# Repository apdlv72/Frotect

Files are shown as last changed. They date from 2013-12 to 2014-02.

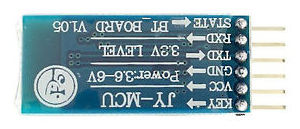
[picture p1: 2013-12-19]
schematic/HC-05/HC-05.JPG

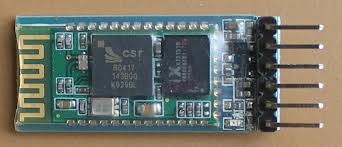
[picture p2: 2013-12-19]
schematic/HC-05/hc-05.jpeg

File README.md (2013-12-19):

Frotect
=======

Arduino sketch to protect sensitive plants from frost damage. Uses DS18B20  temperature sensors and solid state relays to switch light strands on/off.
You need the DallasTemperature arduino library to compile the sketch. 

The device can control up to four strands (however this should not be a hard limit if you are willing to adjust some #defines) and up to 5 sensors.
You can define lower and upper temperature threshold per strand where it should be swicthed on/off. I used it in my garden to protect some young,
exotic plants to survive their first winter in Germany. I mounted the light strips around a simple plastic schaffold and enwrapped the whole setup
with protective popup covers, not only to minimize heat discipation, but also to protect the plants from winter storms and sunshine (yes - that in fact
is the most likely reason for e.g. Olive trees dying in norther areas, not the coldness).

The device will also do some data logging of min/max temperatures, record the duty cycle per strand and even compute overall costs.
The device communicates (actuall it can, there's no need to do so) with the outside world via a Bluetooth module and can be controlled
via simple commands sent to it with a PC/laptop or an Android app. See the folder android for details.

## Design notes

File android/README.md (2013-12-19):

Frotect Android App
=======

This is an Android app that ic capable of connectiong to the Arduino via Bluetooth and control its operation. 
If you are interested in teh Code, feel free to contact me. Did not yet release the code, because I need to
separate the code specific for Frotect from a larger App that I use to control different devices in my house 
(LED strips, garage door opener etc.).

For now you can find some screen shots of the main activity and various config and statistics dialogs.

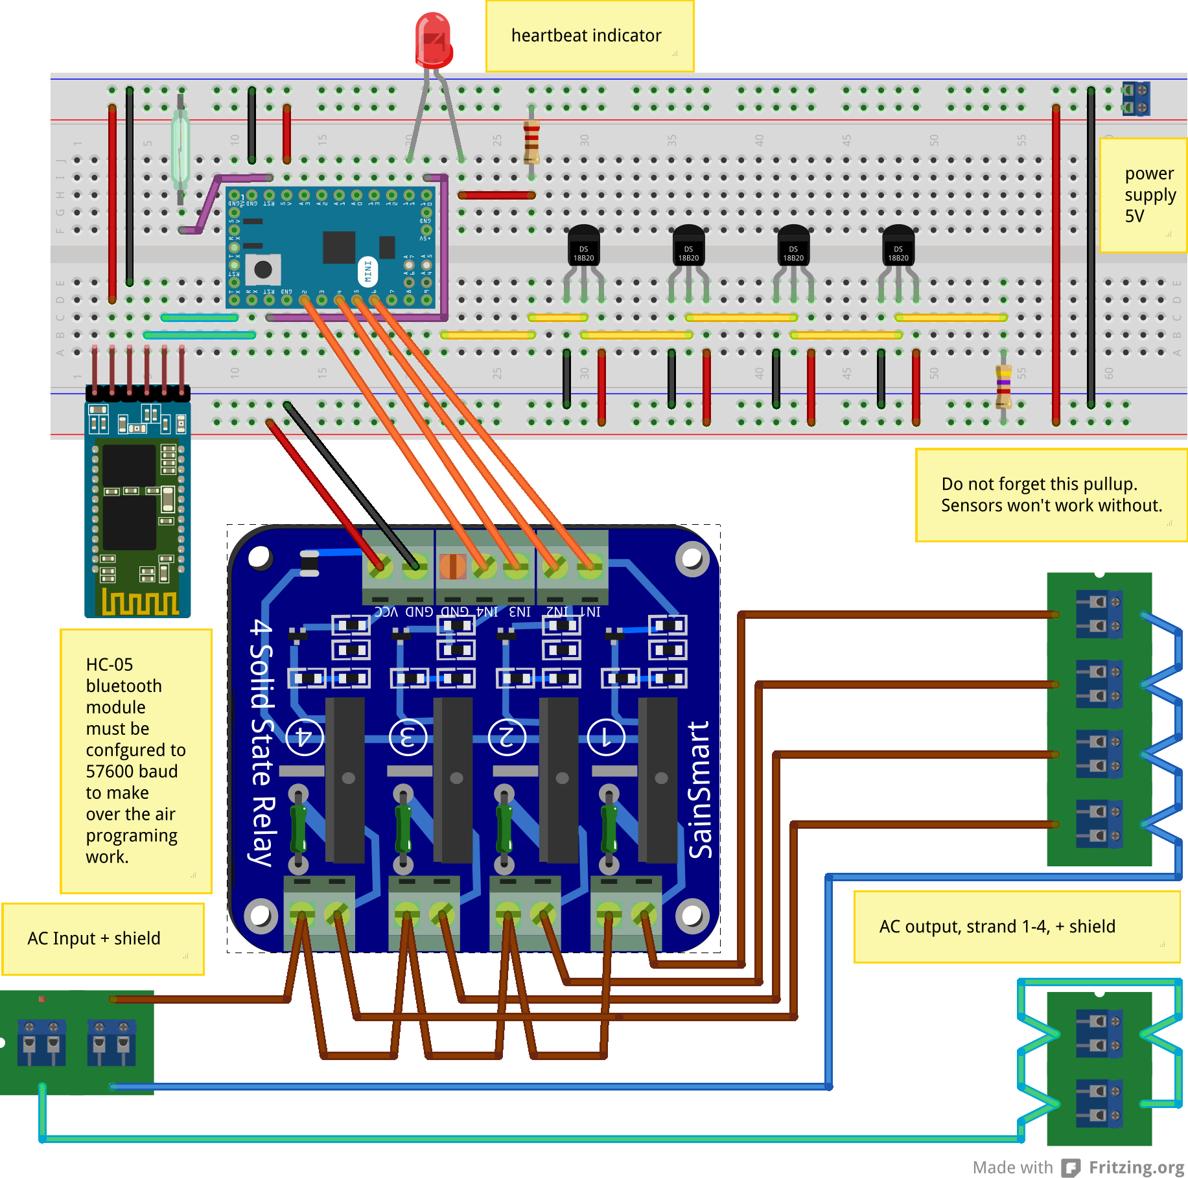
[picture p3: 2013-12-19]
schematic/Frotect.png

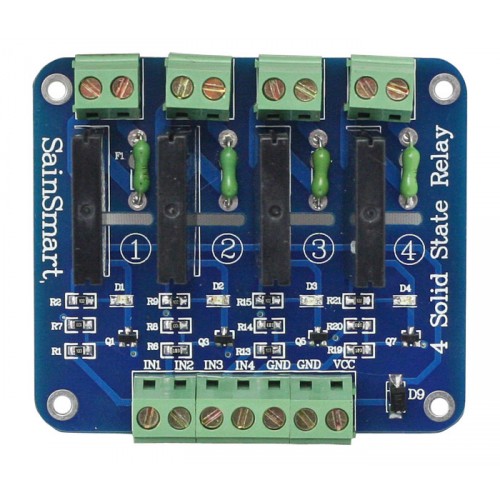
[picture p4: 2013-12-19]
schematic/SainSmart/sainsmart_relay_board.jpg

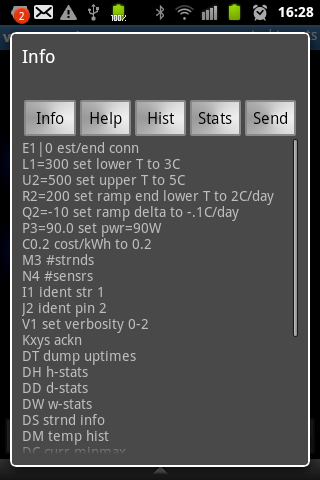
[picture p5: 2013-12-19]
android/screenshots/07_dialog_info.png

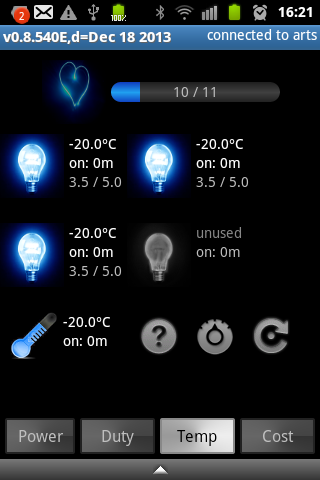
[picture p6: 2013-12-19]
android/screenshots/03_main_connected.png

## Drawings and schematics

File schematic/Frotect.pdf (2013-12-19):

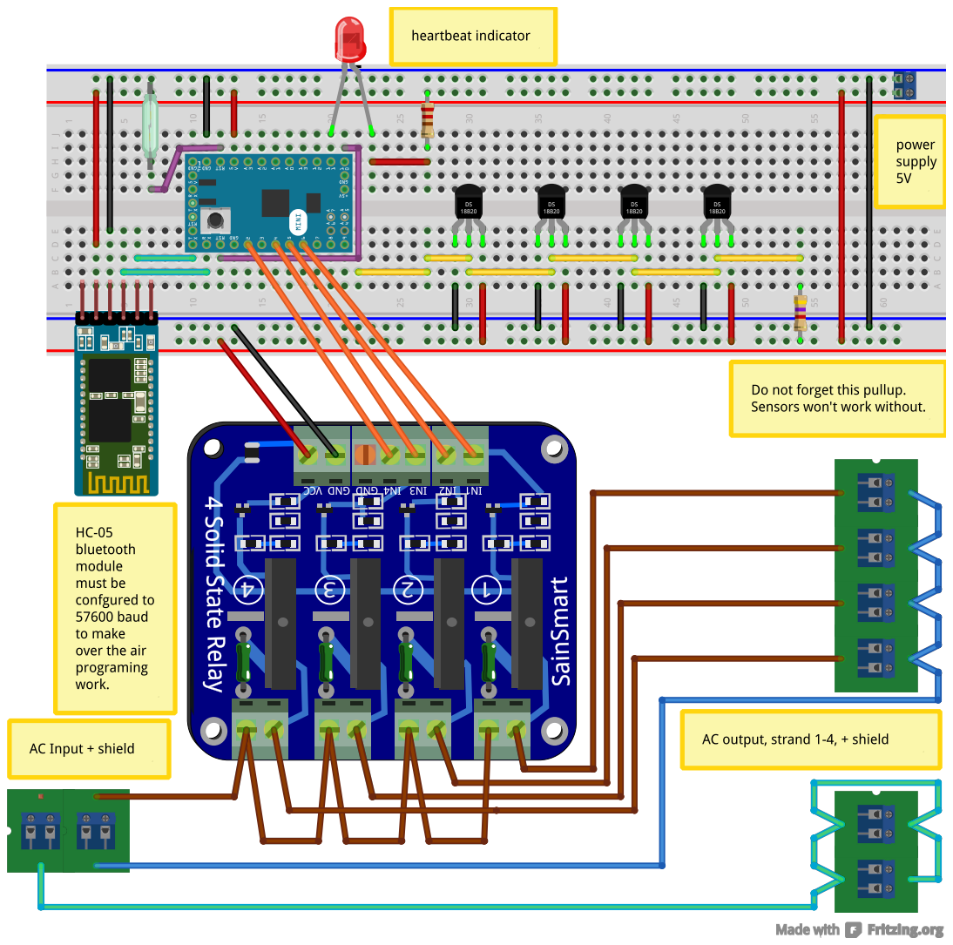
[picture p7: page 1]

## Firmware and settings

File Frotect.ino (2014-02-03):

#include "Frotect.h"

/*
pin-out of sensor connector (top view on jack mounted in housing)
              ___ ___
             /   V   \
yellow/data |  o   o  | orange/Vcc 5V
gren/gnd    |  o   o  | n.c.
             \_______/
              
NOTES:

- External 4.k7 resistor needed between Vcc and data !!!!
- RST pin and GND connected via reed relay for external reset with a magnet.
- RST pin connected back to pin 10 for self-reboot.
- Sensors connected to one-wire bus on pin 9
- Strand relays connected to pins 2, 4, 5, 6, (8 - backup for cable failure)
- External LED connected to 11 (onboard LED pin 13 does not allow PWM)

Sensors:

1.	28;89;48;C8;04;00;00;0E
2.	28;50;81;E1;04;00;00;0E
3.	28;7B;2E;D9;04;00;00;28
4.	00
5.	28;29;7F;C8;04;00;00;87	was strand 4 (former strand 2)
*/

#include <eEEPROM.h>
//#include <MemoryFree.h>

// Workaround for http://gcc.gnu.org/bugzilla/show_bug.cgi?id=34734
// (warning: only initialized variables can be placed into program memory area)
#ifdef PROGMEM
	#undef PROGMEM
	#define PROGMEM __attribute__((section(".progmem.data")))
#endif

#ifdef OSX
#include <math.h>
#endif

///////////////////////////////////////////////////////////////////////////////////
// definitions for compiled in features
#ifdef OSX
	// #define WITH_TIME_LAPSE
	//#define WITH_TIMEWARP
#endif
#define WITH_HEARTBEAT // adds 90 bytes
#define WITH_PING
#define WITH_INDICATE_UPDATE // show "UP. " messages whenthere was a measuring recently
#define WITH_DUMPING // adds   1k code
#define WITH_MIN_MAX // adds 0.8k code + EEPROM data
#define WITH_CURR_MEASURE // dump "MEAS:" info (recent temp. measurements)
#define WITH_HELP
#define WITH_INDICATE_STARTUP // adds 100 bytes code
#define WITH_REAL_SENSORS
#define WITH_SAVE_UPTIME
#define WITH_SERIAL
#define WITH_STATS // adds 4k
#define WITH_SHOW_EVENTS
#define WITH_STRAND_UPDATES
#define WITH_MY_SENSORS // adds 100 bytes
//#define WITH_AUTOCONFIG
//#define WITH_TESTMODE
//#define WITH_DEBUG
//#define WITH_MEMSIZE_DEBUG
///////////////////////////////////////////////////////////////////////////////////

// disable the following info when time lapse enabled (too many otherwise)
#ifdef WITH_TIME_LAPSE
	#undef WITH_INDICATE_UPDATE
	#undef WITH_PING
	#undef WITH_CURR_MEASURE
	#undef WITH_HEARTBEAT
#endif


#ifdef WITH_REAL_SENSORS
  #include <OneWire.h>
  #include <DallasTemperature.h>
#endif

#ifdef OSX
	#if defined constrain
		#undef constrain
		#define constrain(VAL,MIN,MAX) ((VAL)<=(MIN) ? (MIN) : (VAL)>=(MAX) ? (MAX) : (VAL))
	#endif
#endif

// default thresholds for lower/upper temperature hysteresis
#define DEFAULT_LOWER (3.5f)
#define DEFAULT_UPPER (4.5f)


//////////////////////////////////// <prototypes>
// Arduino environment does not require these, however compiler on the Mac
void update_temp_ramping();
static void println_version();
static void eeprom_init();
void reboot();
static void reset();
void save_strand_infos();
void save_sensor(uint8_t i);
void save_sensors();
static float read_cost_per_kWh();
void save_cost_per_kWh100(uint16_t cost_per_kWh100);
void save_number_of_strands(uint8_t m);
void save_number_of_sensors_expected(uint8_t n);
static void set_day_index(uint8_t index);
static void set_week_index(uint8_t index);
static uint8_t get_current_hour();
void set_current_hour(uint8_t index);
void read_hour(uint8_t index, uint8_t strand, s_stats_hour & hour);
void write_hour(uint8_t index, uint8_t strand, s_stats_hour & hour);
void read_day(uint8_t index, uint8_t strand, s_stats_day & day);
void write_day(uint8_t index, uint8_t strand, s_stats_day & day);
void read_week(uint8_t index, uint8_t strand, s_stats_week & week);
void write_week(uint8_t index, uint8_t strand, s_stats_week & week);
uint8_t get_day_index();
uint8_t get_week_index();
static void save_one_week(uint8_t day_start_index);
void save_one_day(uint8_t hour_start_index);
static void dump_stats_hours();
void dump_stats_days();
void dump_stats_weeks();
static void save_statistics();
void set_minmax_index(uint8_t index);
uint8_t get_minmax_index();
static void read_minmax_entry(uint8_t sensor, uint16_t index, s_min_max & mm);
void save_minmax();
void dump_minmax(s_min_max & mm);
void dump_minmax();
void add_ontime(int s, const char * reason);
uint8_t update_history();
void save_uptime();
static boolean check_limits();
void show_string (PGM_P s);
static void dump_help();
static char to_upper(char c);
static boolean dump_strand_infos(boolean updates_only, boolean verbose);
static void dump_strand_info(uint8_t n, s_strand_info & i, boolean single, boolean verbose); //, const char * why);
void dump_general_info();
void compute_temps();
static void update_uptime();
static void blink_pin(uint8_t n, int8_t strand);
void inputClear();
void serialEvent();
static void mydelay(long ms);
boolean sensor_addr_defined(DeviceAddress addr);
static void dump_sensor_address(uint8_t  * addr);
static void dump_sensor(s_sensor_info & sensor);
static void dump_sensors();
void sensors_swap(s_sensor_info & a, s_sensor_info & b);
#ifdef WITH_REAL_SENSORS
int sensor_compare_addr(s_sensor_info & a, s_sensor_info & b);
int sensor_compare(s_sensor_info & a, s_sensor_info & b);
void sensors_sort();
static boolean sensor_replace(s_sensor_info & sensor);
static e_senor_add_result sensor_add(s_sensor_info & sensor, int8_t & at);
#endif
static void sensor_move(uint8_t index, int8_t direct);
static uint8_t sensors_count_available();
static void sensor_unbind(uint8_t i);
static boolean sensor_bind(uint8_t i);
static void sensors_detect();
static void print_lit(uint8_t n, boolean lit);
static void print_hb(uint8_t status, uint8_t cond, int16_t temp); //, byte err, byte cmpl, byte none);
static void flash_status_led(int8_t n);
static void indicate_startup();
boolean sensors_complete();
boolean sensors_none();
void show_status(boolean working);
//int get_free_memory();
void dump_starttime();
void setup();
void loop(void);
int16_t get_hb_temp100();
static void set_status_leds(uint8_t status);
static void set_status_leds_analog(uint8_t value);

#ifdef WITH_AUTOCONFIG
void sensor_get(uint8_t i, s_sensor_info & sensor);
static void auto_config();
#endif

#ifdef WITH_TESTMODE
static void test_mode();
#endif
//////////////////////////////////// </prototypes>


#ifdef OSX
	extern uint8_t doRestart;
#endif

const static uint8_t MAX_HOURS = 24*STATS_PER_HOUR_DAY_COUNT;
const static uint8_t MAX_DAYS  =  7*STATS_PER_DAY_WEEK_COUNT;

typedef enum { V_SILENT=0, V_NORMAL=1, V_VERBOSE=2, V_DEBUG=3 } e_verbosity;
const static e_verbosity V_DEFAULT = V_NORMAL;
static e_verbosity verbosity = V_DEFAULT;

// Data wire is plugged into pin 2 on the Arduino
const static byte PIN_ONE_WIRE_BUS =  9;
const static byte PIN_ONBOARD_LED  = 13;
const static byte PIN_STATUS_LED   = 11;
const static byte PIN_RESET        = 10;

// default pins that connect to the relays controlling the heating strands
static const uint8_t RELAY_PINS[] = { 2, 6, 5, 4, 8 };

//static const s_stats_hour ZERO_HOUR = { current : 1, valid : 0, mins_on : 0 };

#define MAX(A,B) (((A)>(B)) ? (A) : (B))
#define MIN(A,B) (((A)<(B)) ? (A) : (B))

#ifdef WITH_REAL_SENSORS
	// Setup a oneWire instance to communicate with any OneWire devices (not just Maxim/Dallas temperature ICs)
	static OneWire oneWire(PIN_ONE_WIRE_BUS);

	// Pass our oneWire reference to Dallas Temperature.
	static DallasTemperature sensors(&oneWire);
#endif

static boolean eeprom_reset   = false;
static boolean severe_error   = false;
static boolean input_complete = false;

#ifdef WITH_PING
static uint32_t millis_ping     = 0;
#endif

static uint32_t ts_optime       = 0; // total operation time in minutes
static uint32_t ts_starttime    = 0; // current optime when uC started
static uint32_t ts_last         = 0; // last timestanp seen in main loop()

static uint8_t   num_sensors_available = 0;
static uint8_t   num_sensors           = MAX_SENSORS;
static uint8_t   num_strands           = MAX_STRANDS;

#ifdef WITH_SERIAL
static char      input_buffer[16]= { 0 };         // a string to hold incoming serial data
static char    * inputPos  = input_buffer;
static char    * inputEnd  = input_buffer+sizeof(input_buffer)-1;
#endif

static s_strand_info strand_infos[MAX_SENSORS];  // 5*22 = 110 bytes (in RAM ,not EEProm)

#ifdef WITH_STATS
static s_stats_hour  current_stats[MAX_STRANDS];
#endif

static s_curr_minmax current_minmax[MAX_SENSORS];

static const s_eeprom_data * EE = 0;
eEE_CHECKSIZE(*EE); 

//const  uint16_t MAGIC = 0x2347;
// Magic number to write to the beginniing of EEProm to check whether it was initialized before.
// The value will change whenever n umber of sensors or strands was changed or when
// the structure s_eeprom_data has been changed significantly (thus the position ofstrand_infos changed).
const  uint16_t MAGIC = (uint16_t)((MAX_SENSORS<<12) + (MAX_STRANDS<<8) + (long)&(EE->strand_infos));


#define BZERO(TOKEN) memset(&(TOKEN), 0, sizeof((TOKEN)))

static const int16_t MIN_TEMP = -200;
static const int16_t MAX_TEMP =  300;

static uint16_t curr_op_day()
{
	return ts_optime/(24*60);
}

static int16_t to_temp100(float f)
{
	f = constrain(f, MIN_TEMP, MAX_TEMP);
	// do NOT use round() here (adds almost 100 bytes of code)
	int16_t i = 100*f;
	return i;
}

//uint8_t to_eeprom_watts(int16_t w)
//{
//	return constrain(w/2, 0, 255);
//}

static void from_eeprom(s_strand_info_eeprom &ee, s_strand_info &ram)
{
	ram.temp_lower100         = ee.temp_lower_start100;
	ram.temp_upper100         = ee.temp_upper_start100;
	ram.watts2                = ee.watts2;
	ram.sensor                = ee.sensor;
	#ifdef WITH_TEMP_RAMPING
	// initial call to update_temp_ramping() in setup() will update
	// temp_lower100 and temp_upper100 according to ramping settings
	ram.temp_lower_start100   = ee.temp_lower_start100;
	ram.temp_ramping_limit100 = ee.temp_ramping_limit100;
	ram.ramp_start_day        = ee.ramp_start_day;
	ram.ramp_per_day_temp100  = ee.ramp_per_day_temp100;
	#endif
}

static void to_eeprom(s_strand_info &ram, s_strand_info_eeprom &ee)
{
	ee.temp_lower_start100   = ram.temp_lower100;
	ee.temp_upper_start100   = ram.temp_upper100;
	ee.watts2                = ram.watts2;
	ee.sensor                = ram.sensor;
	#ifdef WITH_TEMP_RAMPING
	ee.temp_lower_start100   = ram.temp_lower_start100;
	ee.temp_ramping_limit100 = ram.temp_ramping_limit100;
	ee.ramp_start_day        = ram.ramp_start_day;
	ee.ramp_per_day_temp100  = ram.ramp_per_day_temp100;
	#endif
}


#ifdef WITH_MY_SENSORS
// This is my own sensor configuration. Using WITH_MY_SENSORS will avoid
// that sensors get rescanned in a different order after substantial reprogramming of
// the Arduino (i.e. if it was necessary to erase EEProm because of major changes)
//1.	28;89;48;C8;04;00;00;0E
//2.	28;29;7F;C8;04;00;00;87	was strand 4 (former strand 2)
//3.	28;7B;2E;D9;04;00;00;28
//4.	00
//5.	28;50;81;E1;04;00;00;6E

static const DeviceAddress MY_SENSORS[]  =
{
  { 0x28, 0x89, 0x48, 0xC8, 0x04, 0x00, 0x00, 0x0E },
  { 0x28, 0x29, 0x7F, 0xC8, 0x04, 0x00, 0x00, 0x87 },
  { 0x28, 0x7B, 0x2E, 0xD9, 0x04, 0x00, 0x00, 0x28 },
  { 0x00, 0x00, 0x00, 0x00, 0x00, 0x00, 0x00, 0x00 },
  { 0x28, 0x50, 0x81, 0xE1, 0x04, 0x00, 0x00, 0x6E }
};

static void mysensors_init()
{
	//const boolean debug = false;
	//if (debug) { PPRINTLN("D.mysensors_init"); dump_sensors(); }
	for (uint8_t s=0; s<MAX_SENSORS; s++)
	{
		s_strand_info & strand = strand_infos[s];
		memcpy(strand.sensor.address, MY_SENSORS[s], sizeof(DeviceAddress));
		strand.sensor.bound = strand.sensor.used = sensor_addr_defined(strand.sensor.address);
	}
	//if (debug) { dump_sensors(); PPRINTLN("D./mysensors_init");  }
}
#endif // WITH_MY_SENSORS


static void eeprom_init()
{
	//const boolean debug = false;
	//if (debug) PPRINTLN("D.eeprom_init");

	uint16_t magic = eEE_READN(EE->magic);
	BZERO(strand_infos);

	PPRINT("MAGIC."); Serial.print(magic, HEX);
	if (MAGIC!=magic)
	{
		PPRINTLN(".inv");

		magic = MAGIC;
		update_uptime(); // this will set: ts_optime = approx. 0;
		ts_last = 0;

		#ifdef WITH_STATS
		eEE_ZERO(EE->statistics);
		#endif
		eEE_ZERO(EE->temp_histories);
		eEE_ZERO(EE->start_hours);

		save_number_of_strands(MAX_STRANDS);
		// by default expect one sensor per strand thus no extra (unbound) sensors
		save_number_of_sensors_expected(MAX_STRANDS);

		save_cost_per_kWh100(25*100); // 2500 = 25 cents/kWh
		save_uptime();
		set_day_index(0);
		set_week_index(0);
		set_minmax_index(0);
		set_current_hour(MAX_HOURS-1);

		for (uint8_t s=0; s<MAX_SENSORS; s++)
		{
			s_strand_info & strand = strand_infos[s];
			strand.temp_lower100         = 350; // DEFAULT_LOWER; // 3.0f;
			strand.temp_upper100         = 500; // DEFAULT_UPPER; // 5.0f;
			// my 2nd (s=1) strand has 16W/m and is 9 meters long, other strands are 6m*16.1W,
			// there are four strands however connected to first relay
			switch (s)
			{
			case 0 : strand.watts2 = (4*97)/2; break; // 4 strands a 97W on relay 1
			case 1 : strand.watts2 = 144/2;    break; // 9m a 16 strand on relay 2
			default: strand.watts2 = (97+1)/2; break; // 97W strands on relay 2/3
			}
			strand.pin                   = RELAY_PINS[s];
			strand.ts_last_change        = ts_optime;
			strand.update                = 1; // make sure it gets dumped initially
			#ifdef WITH_TEMP_RAMPING
			strand.temp_lower_start100   = 350;
			strand.temp_ramping_limit100 = 250;
			strand.ramp_start_day        = curr_op_day();
			strand.ramp_per_day_temp100  = -25; // decrease limits by 0.2C per day
			#endif
		}

		#ifdef WITH_MY_SENSORS
		mysensors_init();
		#endif

		save_strand_infos();

		eEE_WRITEN(EE->magic, magic);
		eeprom_reset = true;
	}
	else
	{
		PPRINTLN(".val");

		num_sensors = eEE_READN(EE->num_sensors);
		num_sensors = MIN(num_sensors, MAX_SENSORS);

		num_strands = eEE_READN(EE->num_strands);
		num_strands = MIN(num_strands, MAX_STRANDS);

		ts_optime = eEE_READN(EE->optime_minutes);
		ts_last = ts_optime;

		for (uint8_t s=0; s<MAX_SENSORS; s++)
		{
			s_strand_info & strand = strand_infos[s];

			// read into the struct that represents the strand in eeprom
			s_strand_info_eeprom ee;
			eEE_READ(EE->strand_infos[s], ee);

			// and convert to the representation in RAM
			from_eeprom(ee, strand);

			strand.pin            = RELAY_PINS[s];
			strand.ts_last_change = ts_optime;
			strand.update         = 1; // make sure it gets dumped initially
			//strand.lit          = 0;
			//strand.sensor.avail = 0;
		}
	}

	//if (debug) PPRINTLN("D./eeprom_init");
}

void reboot()
{
	#ifdef OSX
		doRestart = true;
	#else
        digitalWrite(PIN_RESET, LOW);
        asm volatile ("jmp 0");
	#endif
}

static void reset()
{
    // explicit cast necessary to uint16_t to make the templating work
	uint16_t wrong_magic = 0xffff;
	#ifdef OSX
	fprintf(stderr, "OSX: WRITING WRONG MAGIC %x\n", wrong_magic);
	#endif
	eEE_WRITEN(EE->magic, wrong_magic);
	reboot();
}

void save_strand_infos()
{
	// takes 90 * 3.3ms = 297ms to complete
	for (uint8_t i=0; i<MAX_SENSORS; i++)
	{
		s_strand_info & strand = strand_infos[i];
		s_strand_info_eeprom ee;
		to_eeprom(strand, ee);
		eEE_WRITE(ee, EE->strand_infos[i]);
	}
}

void save_sensor(uint8_t i)
{
	// take 9 * 3.3ms = 30ms to complete
	eEE_WRITE(strand_infos[i].sensor, EE->strand_infos[i].sensor);
}

void save_sensors()
{
	// take 4 * 9 * 3.3ms = 118ms to complete
	 for (uint8_t i=0; i<MAX_SENSORS; i++) save_sensor(i);
}

static float read_cost_per_kWh()
{
	uint16_t cost_per_kWh100;
	cost_per_kWh100 = eEE_READN(EE->cost_per_kWh100);
	return 0.01*cost_per_kWh100;
}
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
void loop()
{
	//PPRINT("ts_optime: "); Serial.println(ts_optime);
	show_status(true);

	// Check update flags on strands, dump status if so and reset the flag.
	// This will assert continuous status updates to the mobile app.
	#ifdef WITH_STRAND_UPDATES
	if (dump_strand_infos(true, false))
	{
		//PPRINTLN("EV. e=strands.chg");
	}
	#else
	#warning STRAND UPDATES NOT SHOWN !!!!!!
	#endif


	// check the temperature limits when the current ts changed (thus every full minute)
	if (ts_last==ts_optime) // minute did not change
	{
		long pause_len = MILLIS_PER_UPTIME/3;

		// if we're missing sensors, re-check as often as possible
		if (!sensors_complete())
		{
			if (verbosity>V_SILENT)
			{
				PPRINTLN("EV.e=sens.redetect");
			}
			sensors_detect();
			pause_len = 10000; // retry in 10s
		}

		// start measuring the temepratures only if heartbeat is currently not beating
		// (i.e. showing steady state 0=LED lit) otherwise the animation will become a little bit bumpy
		boolean do_compute_temps = true;
		#ifdef WITH_HEARTBEAT
		do_compute_temps = (hb.last_status==0);
		#endif
		if (do_compute_temps)
		{
			compute_temps();
		}

		if (sensors_none() || severe_error)
		{
			pause_len = 500;
		}

		show_status(false);

		// wait a tiny amount of time if there was no measure
		//PPRINT("D. mydelay "); Serial.println(pause_len);
		mydelay(pause_len);
	}
	else // minute changed
	{
		ts_last = ts_optime;

		if (0==(millis()/10000))
		{
			if (severe_error)
			{
				PPRINTLN("E.NODATA");
			}
		}

		// if we're missing sensors, re-check every 15 minutes
		if (!sensors_complete() && 0==ts_optime%5)
		{
			sensors_detect();
		}

		boolean change = check_limits();
		// "UP." stand for (possibly) update (of the strand states)
		#ifdef WITH_INDICATE_UPDATE
		PPRINT("UP.chng="); Serial.print(change); PPRINT(",t="); Serial.println(0.001f*millis());
		#endif
		if (change)
		{
			dump_current_stats();
		}

		uint8_t rc = update_history();
		#ifdef WITH_SHOW_EVENTS
		if (HIST_UPD_NONE!=rc)
		{
			if (verbosity>V_SILENT)
			{
				PPRINT("EV.e=hist.updtd,reas=");
				switch (rc)
				{
				case HIST_UPD_1ST : PPRINTLN("init"); break;
				case HIST_UPD_MIN : PPRINTLN("min"); break;
				case HIST_UPD_MAX : // fall through
				default:            PPRINTLN("max"); break;
				}
			}
		}
		#endif

		// update stats every full hour. since actual write cycles are distributed equally
		// over MAX_HOURS (24) entries (see: s_stats_hour), there is only 1 write cycle per day
		// thus max. write cycles now exceeded before 270 years
		//if (0==ts_optime%60)
		if (0==ts_optime%60)
		{
			save_statistics();
			#ifdef WITH_SHOW_EVENTS
			if (verbosity>V_SILENT)
			{
				PPRINTLN("EV.e=stats.savd");
			}
			#endif

			#ifdef OSX
			usleep(30000);
			#endif
		}

		// save history every MMHIST_INTERVAL (6) hours means 4 writes a day to the index (hist_count)
		// and will not exceed max. write cycles before approx. 68 years (4*365*68 = 99348)
		//printf("t till next save_minmax: %i\n", MMHIST_INTERVAL*60-ts_optime%(MMHIST_INTERVAL*60));
		if (0==ts_optime%(MMHIST_INTERVAL*60))
		{
			#ifdef WITH_TEMP_RAMPING
			update_temp_ramping();
			#endif

			save_uptime();
			save_minmax();
			#ifdef WITH_SHOW_EVENTS
			if (verbosity>V_SILENT)
			{
				PPRINTLN("EV.e=hist.savd");
			}
			#endif
		}

		show_status(false);
	}

	check_serial();
	update_uptime();
}


//////////// unused stuff


#ifdef WITH_MEMSIZE_DEBUG
extern int __bss_end;
extern void *__brkval;

int get_free_memory()
{
  int free_memory;

  if((int)__brkval == 0)
	free_memory = ((int)&free_memory) - ((int)&__bss_end);
  else
	free_memory = ((int)&free_memory) - ((int)__brkval);

  return free_memory;
}
#endif

#ifdef WITH_AUTOCONFIG
void sensor_get(uint8_t i, s_sensor_info & sensor)
{
	sensor = strand_infos[i].sensor;
}


static void auto_config()
{
	compute_temps();

	int8_t T[num_sensors_available];
	int8_t result[num_strands];

	for (uint8_t j=0; j<num_sensors_available; j++)
	{
		T[j] = strand_infos[j].curr_temp;
	}

	for (uint8_t i=0; i<num_strands; i++)
	{
		result[i] = -1;

		PPRINT("AUTOCONF: n=");  Serial.println(i+1);

		s_strand_info_eeprom & s = strand_infos[i];
		pinMode(s.pin, OUTPUT);
		digitalWrite(s.pin, HIGH);

		uint32_t ts_timeout = millis()+30*1000;
		int8_t found = -1;
		while (found<0 && millis()<ts_timeout);
		{
			delay(1000);
			compute_temps();

			for (int j=0; j<num_sensors_available; j++)
			{
				// check if temp. increased by 1 degrees
				if (strand_infos[j].curr_temp>T[j]+2*1)
				{
					found = j;
				}
			}
		}

		if (found<0)
		{
			PPRINT("AUTORES. n="); Serial.print(i+1); PPRINTLN(", sens=none");
		}
		else
		{
			PPRINT("AUTORES. n="); Serial.print(i); PPRINT(", sens="); Serial.println(found);
			T[found] -= 10;
			result[i] = found;
		}
	}

	s_sensor_info sensor_infos_new[MAX_SENSORS];
	for (uint8_t i=0; i<num_strands; i++)
	{
		int j = result[i];
		if (j>-1)
		{
			s_sensor_info s;
			sensor_get(j, s);
			sensor_infos_new[i] = s;
		}
	}

	PPRINTLN("AUTOCONF!");
}
#endif


#ifdef WITH_TESTMODE

boolean isTestModeActive = false;

static void test_mode()
{
	if (isTestModeActive)
	{
		isTestModeActive = 0;
		return;
	}

	isTestModeActive = 1;

	PPRINTLN("TM:for 5 minutes\n");
	PPRINTLN("TM:Heat up by 1C to lights strand");

	compute_temps();
	uint32_t ts_end = millis()+2*60*1000L; // "now" plus 120seconds

	float T[num_sensors_available];
	for (uint8_t i=0; i<num_sensors_available; i++)
	{
		T[i] = strand_infos[i].curr_temp;
	}

	while (isTestModeActive && millis()<ts_end)
	{
		mydelay(1000); // will handle serial command end possible reset "isTestmodeActive"
		compute_temps();

		for (uint8_t i=0; i<num_sensors_available; i++)
		{
			int8_t t = strand_infos[i].curr_temp;
			PPRINT("TMRES.n="); Serial.print(i+1); PPRINT(", t="); Serial.print(0.5*t); PPRINT(" (init: "); Serial.print(0.5*T[i]); PPRINT(") ");

                        int pin   = strand_infos[i].pin;
			int level = (t>T[i]+2.0) ? HIGH : LOW;

                        pinMode(pin, OUTPUT);
			digitalWrite(pin, level);
                        PPRINT(" pin "); Serial.print(pin); PPRINT(" -> "); Serial.println(level);

                        if (HIGH==level) ts_end = millis()+2*60*1000L;
                        PPRINT("TM: ms left: "); Serial.println(ts_end-millis());
		}
	}

	PPRINTLN("TM!");
	isTestModeActive = false;
}
#endif

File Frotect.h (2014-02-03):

// Only modify this file to include
// - function definitions (prototypes)
// - include files
// - extern variable definitions
// In the appropriate section
#ifndef FrostProtect_H_
#define FrostProtect_H_

#include "Arduino.h"

#include <DallasTemperature.h>

#ifdef OSX
	#define MAX_STRANDS 4
	#define MAX_SENSORS 5
#else
	#define MAX_STRANDS 4
	#define MAX_SENSORS 5
#endif

// min/max. temperature history length
#define STATS_PER_HOUR_DAY_COUNT 2
#define STATS_PER_DAY_WEEK_COUNT 2

// maximum number of weeks, per-hour stats should be recorded for
//#define MAX_WEEKS 5 // for testing
#define MAX_WEEKS 30 // more than half a year

// record min/max temp. per sensor every 6 hours (do not reduce .... eeprom write cycles!)
#define MMHIST_INTERVAL 6

// record min/max temperatures for the last 12 days
#ifdef OSX
  #define MMHIST_DAY_COUNT 11
#else
  #define MMHIST_DAY_COUNT  11
#endif
#define TEMP_HIST_LEN (24/MMHIST_INTERVAL*MMHIST_DAY_COUNT)


#if TEMP_HIST_LEN>255
#error TEMP_HIST_LEN exceeds data range 0-255
#endif

#define WITH_TEMP_RAMPING


#define MAX_START_HOURS 15
typedef struct
{
	uint8_t  idx;
	uint16_t hours[MAX_START_HOURS];
} s_start_hours; // 81 bytes

typedef struct
{
	uint8_t       used  : 1;
	uint8_t       avail : 1;
	uint8_t       bound : 1;
	DeviceAddress address;
} s_sensor_info; // 9 bytes

typedef struct s_strand_info_eeprom
{
  public:

	// Since this info goes to EEProm, values are stored as 100*value in C, e.g. 350 means 3.5C.
	// Range -32768,...,32767 thus corresponds to limits -327C,...,327C
	int16_t  temp_lower_start100; // lower limit that will cause strand to light up
	int16_t  temp_upper_start100; // upper limit that will cause power down
	// power consumption stored in 2*watts, e.g. a value of 200 means 400W
	uint8_t  watts2;
	// 1+1+1 = 2 bytes

	s_sensor_info sensor;
	// 2+10 = 12 bytes

	#ifdef WITH_TEMP_RAMPING
	// day (thus tp_optime/1440) when ramp down phase started:
	uint16_t ramp_start_day;
	// 12+4 = 16 bytes
	// 100*C the value to increase/decrease temperature per day for ramp up/down.
	// The range -128,...,127 corresponds to -1.28,...,1.27C als allows e.g. to
	// ramp up/down the thresholds by almost 13C in ten days
	int8_t   ramp_per_day_temp100;
	// 16+1 = 17 bytes

	// lower limit end   value for ramping
	int16_t  temp_ramping_limit100 ; // lower limit end value for ramping
	#endif
} s_strand_info_eeprom; // 17 bytes


// s_strand_info inherits everything from s_strand_info_eeprom but adds those members
// that does not need to go to EEProm
struct s_strand_info //: s_strand_info_eeprom
{
  public:
	// below values are the same as in s_strand_info_eeprom
	int16_t       temp_lower100;
	int16_t       temp_upper100;
	uint8_t       watts2;
	s_sensor_info sensor;
	#ifdef WITH_TEMP_RAMPING
	uint16_t      ramp_start_day;
	int8_t        ramp_per_day_temp100;
	// same as s_strand_info_eeprom till here: 17 bytes
	int16_t       temp_lower_start100; // lower limit start value for ramping
	// lower/upper limit end value for ramping down/up
	int16_t       temp_ramping_limit100 ;
	#endif

	byte  lit        : 1; // status: light strand lit or off
	byte  update     : 1; // temperature or status changes -> print update
	byte  temp_valid : 1; // whether temperature measure was valid
	byte  pin        : 5; // pin this strand is connected to (0-31)
	// 17+1 = 18 bytes

	// Temperatures are stored as 100*value in celsius, e.g. 350 means 3.5C.
	// Total range is -160C,...,160C therefore and should be sufficient for "normal" environments.
	//int16_t  curr_temp100;
	int16_t curr_temp100;
	// 18+4 = 22 bytes

	// last time stamp when status changed:
	uint32_t ts_last_change;
	// 22+4 = 26 bytes

	// total number of errors on the sensor bound to this strand
	uint8_t  errors;
	// 26+1 = 27 bytes
};
typedef struct s_strand_info s_strand_info;


typedef struct  // 1 byte
{
	// This bits marks the entry in the array of hours which corresponds to the current hour.
	// Moving to the next hour means to update 4 bytes in EEProm - the former hour and the next hour
	// and spreads write cycles equally over the array of hours rather than writing continuously to
	// the same cells if an index was used. Using this flag means that every cell in this array will
	// be modifies at most once per day and will exceed max. write cycles after 100k/265=273 years.
	uint8_t current  : 1;
	uint8_t valid    : 1;
	uint8_t mins_on  : 6; // 2^6-1=63 > 60 m/h
} s_stats_hour;


typedef struct  // 2 bytes
{
	uint16_t valid   : 1;
	uint16_t mins_on : 15; // 2^16-1=65535 > 24*60=1440 m/d
} s_stats_day;

typedef struct  // 1 byte
{
	uint8_t valid      : 1;
	uint8_t hours2_on  : 7; // 127 > 7*24/2=84 h/week
} s_stats_week;

typedef struct
{
	s_stats_hour hours[24*STATS_PER_HOUR_DAY_COUNT]; // 24*1 bytes = 24
	s_stats_day  days[7*STATS_PER_DAY_WEEK_COUNT];   // 28*2 bytes = 56
	s_stats_week weeks[MAX_WEEKS]; // 24*1 bytes = 24
	// 24+56+24 = 104
} s_statistics; // total: 104 bytes

// temperature history saved in EEProm (requires 2 bytes only)
typedef struct
{
	int8_t  min2;      // -128,...,127 -> -64C,...,63.5C
	// max := min+diff
	uint8_t diff2 : 7; // 0,...,127 -> 0,...,63C (on top of min)
	uint8_t valid : 1;
} s_min_max; // 2 bytes

// temperature min/max for current hour (requires 4 bytes)
typedef struct  // 1 byte
{
	byte    valid  : 1;
	int16_t curr_min100; // -32768,...,32767 -> -327C,...,327C
	int16_t curr_max100; // -32768,...,32767 -> -327C,...,327C
} s_curr_minmax;

typedef struct
{
	s_min_max data[TEMP_HIST_LEN];
}
s_temp_history; // (24/6)*7*2 bytes = 56 bytes

// contains everything that goes to EEprom
typedef struct
{
	uint16_t       magic;            // 2 bytes
	uint8_t        num_sensors;
	uint8_t        num_strands;
	uint32_t       optime_minutes;   // 4 bytes (sufficient for 8000 years)
	uint16_t       cost_per_kWh100;  // 100*cost in cent per kWh
	uint8_t        day_count;        // 1 byte: 0-28
	uint8_t        week_count;       // 1 byte: 0-16
	uint8_t        hist_count;       // 1 byte
	s_strand_info_eeprom  strand_infos[MAX_SENSORS];  // 4*22 =  88 bytes
	s_statistics          statistics[MAX_STRANDS];    // 4*96 = 384 bytes
	s_temp_history        temp_histories[MAX_SENSORS]; // 5*56 bytes = 280
	s_start_hours         start_hours;
} s_eeprom_data; // 998 bytes < 1024


typedef enum { SENSOR_KNOWN, SENSOR_ADDED, SENSOR_IGNORED } e_senor_add_result;

// If the compiler complains about an error here (overflow in array dimension),
// the reason is that the size of s_eeprom_data excceds the EEPROM capacity.
// Try to reduce STATS_PER_HOUR_DAY_COUNT/7*STATS_PER_DAY_WEEK_COUNT/MAX_WEEKS or MMHIST_DAY_COUNT in this case.
struct FailsIfEEPromExceeded
{
	int c[E2END-sizeof(s_eeprom_data)];
};
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

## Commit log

2013-12-19 Initial checkin.
    [Frotect.fzz]
2013-12-19 Fixed: Header file changed and include failed
    [Frotect.ino]
2014-01-21 Fixed: Missing time unit in First line of temperature history
    [Frotect.ino]
2014-02-03 Changed definition of power consumtion to cover more than 255W per strand
2014-02-24 Removed own Makefile after Oxduino's works with NecIR as well
    [Frotect2.fzz]
2014-02-24 Deleted schematic/.DS_Store
